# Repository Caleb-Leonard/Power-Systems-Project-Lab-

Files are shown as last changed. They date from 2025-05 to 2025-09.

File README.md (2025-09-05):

# Power Systems Project Lab
## Microcontroller Buck Converter Design
The project description given was to build an adjustable DC-DC buck converter with digital control from a microcontroller to be able to power a range of devices. 
It was decided the input voltage of the converter would be 8-14 V with an output range of 2.5-5.5 V at 2 A max.\
Originally, a basic buck converter was designed with an input capacitor, MOSFET, diode, and output LC filter commonly seen in most power electronics theory examples.

The next addition to the design was a MOSFET gate driver (First the Infineon IR2125, then the Onsemi NCP5901).

The next iteration included:\
  -Pi LC EMI filter between the power source and the high side MOSFET\
  -Input negative thermal coefficient (NTC) resistor to limit inrush current\
  -Input/output current sensing with Monolith Power Systems MCS1806 Linear Hall Effect Current Sensor\
  -Input/output voltage sensing with Analog Devices LT1112 Low Power Precision Amplifier\
  -Changed Onsemi NCP5901 MOSFET Gate Driver to Onsemi NCP3420 to better fit ESP32 logic level voltages
  
Finally, the design was changed to replace parts mentioned above:\
  -Texas Instruments INA219 for current sensing\
  -Texas Instruments INA157 for voltage sensing\
PCB was designed to be 2-layer to minimize cost, manufacturing difficulty, 

Future work includes:\
  -MOSFET gate driver redesign\
  -Change microcontroller from ESP32 to Arduino Nano (Preferably IoT version)\
  -Redesign PCB
    -Inductor component replacement and relocation\
    -Decrease EMI filter current loop area\
    -Add testpoints/vias/pads\
    -Use copper pours for input/output connectors to decrease resistance\
    -Add more documentation/notes to board sikscreen\
  -Finish automated test equipment (ATE) programs

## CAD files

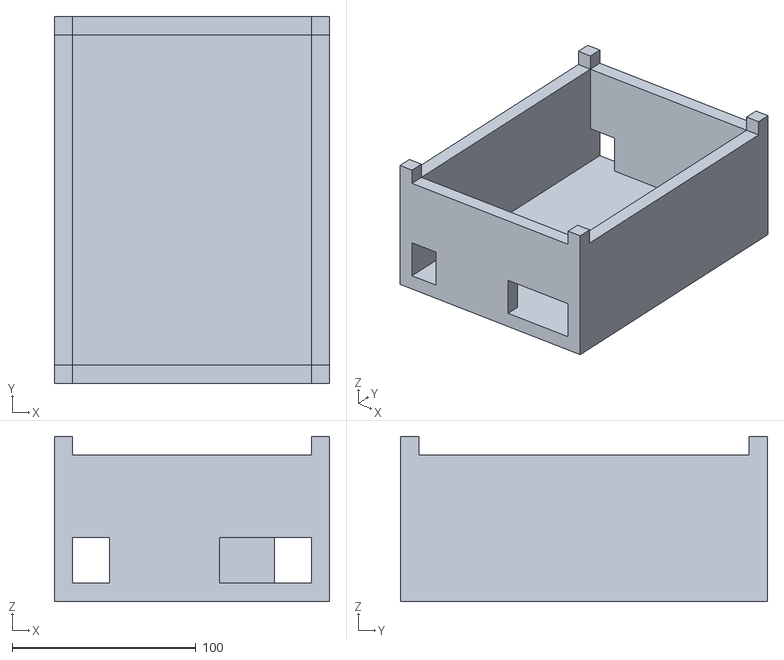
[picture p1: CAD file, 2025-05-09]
Buck Converter Project Box.stl
150.0 x 200.0 x 90.0

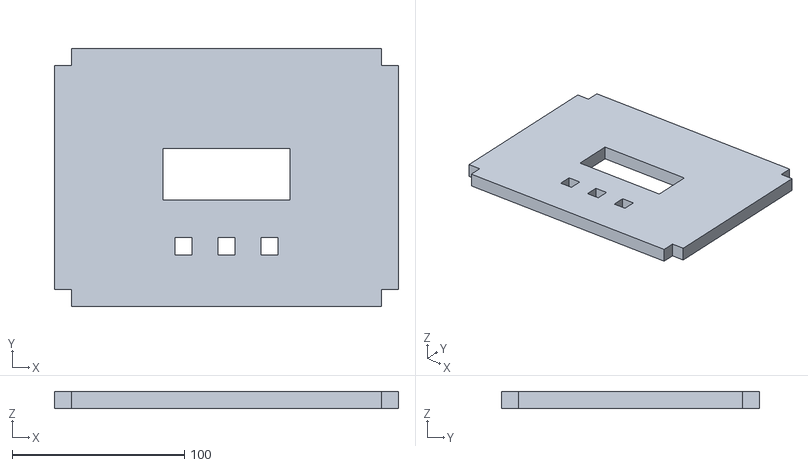
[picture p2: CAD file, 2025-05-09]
Buck Converter Project Box - Top.stl
200.0 x 150.0 x 10.0

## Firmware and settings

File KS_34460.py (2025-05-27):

#Author: Caleb Leonard
#Use: PyVisa to control Keysight 34460 Digital Multimeter
#Multimeter Programmer's Manual: https://www.keysight.com/us/en/assets/9018-04842/service-manuals/9018-04842.pdf
#PyVISA Library Docs: https://pyvisa.readthedocs.io/en/stable/index.html

import pyvisa as pyv

rm = pyv.ResourceManager()
instr = rm.list_resources()

def DMMConnect(address):
	adg = rm.open_resource(address)
	print(adg.query("*IDN?"))
	return adg

def Save_Display(inst):
	command = "HCOPy:SDUMp:FORMat PNG"
	inst.write(command)
	command = "HCOPy:SDUMp:FORMat? "
	inst.query(command)

def Measure_Current(inst):
	command = "MEASure[:PRIMary]:CURRent:[:DC]?"
	inst.query(command)

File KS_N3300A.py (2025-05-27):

#Author: Caleb Leonard
#Use: PyVisa to control Keysight N3300A
#Electronic Load Programmer's Manual: https://www.keysight.com/us/en/assets/9018-01307/programming-guides/9018-01307.pdf?success=true
#PyVISA Library Docs: https://pyvisa.readthedocs.io/en/stable/index.html

import pyvisa as pyv

rm = pyv.ResourceManager()
instr = rm.list_resources()

def ELoadConnect(address):
	adg = rm.open_resource(address)
	print(adg.query("*IDN?"))
	return adg

#WIP
def Source_Current(inst)
	command = 
	inst.write(command)

#WIP
def Source_Resistance(inst)
	command = 
	inst.write(command)

#WIP
def Source_Voltage(inst)
	command = 
	inst.write(command)

#WIP
def Measure_Power(inst)
	command = 
	power = 
	return power

#WIP
def Measure_Current(inst)
	command = 
	current = 
	return current

#WIP
def Measure_Voltage(inst)
	command = 
	voltage = 
	return voltage

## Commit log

2025-03-10 Libraries for SCPI Commands
    Keysight MSOX3034 OSCOPE, E36311 Power Supply, 33500 Waveform Generator
2025-05-09 Added stl files for 3D printed converter case
    [Buck Converter Project Box - Top.stl, Buck Converter Project Box.stl]
2025-05-28 Buck Converter PCB Fusion 360 Zip
    Has gerber, gerber job, assembly, and drill files for buck converter PCB
2025-05-31 First Buck Converter LTSPICE Model
2025-06-10 SCPI Instrument Automation Jupyter Notebook
    Cell 1 is used for basic connection, debugging, and measurement of lab instruments.
    Cell 2 is used to debug specifically Keysight EDUX1052 oscilloscope Python and SCPI programming.
    Cell 3 used for closer conditions to final testing conditions
    Cell 4: PWM Frequency Testing; Measure converter ripple at different pwm frequencies starting from 50 kHz, stepping 10 kHz, and stopping at 200 kHz.
    Cell 5: PWM Duty Cycle Testing; Measure converter output voltage at different pwm duty cycles starting from 10%, stepping 5%, and stopping at 90%.
    Cell 6: Efficiency Testing; Measure converter efficiency at different input voltages starting from 8 V, stepping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
